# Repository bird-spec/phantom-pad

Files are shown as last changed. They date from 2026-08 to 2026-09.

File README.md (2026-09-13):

# phantom pad

this is the pcb for my phantom macropad. it's a little keyboard that doubles as a controller for my drone. twelve mechanical keys in a 3x4 matrix plus two rotary encoders, all running off a seeed xiao

the whole point is one board that's both a keyboard and a flight controller. rotate the encoders for throttle and yaw, and the four keys around each one act like a d-pad for direction. slide the top section off and it's just a normal macropad again

it's a two layer board. i wired the switches in a matrix so twelve keys only need seven pins instead of twelve, which left enough pins free for the two encoders. every switch has a diode so pressing three keys at once doesn't register a fourth one that isn't pressed

this was my first pcb ever. i learned kicad from nothing to make it. the hardest part was the routing, and figuring out that a matrix needs the rows and columns to actually reach the microcontroller, which sounds obvious but isn't when you're staring at a wall of green lines

made with the seeed xiao, cherry mx footprints, and alps ec11 encoders. firmware runs on qmk



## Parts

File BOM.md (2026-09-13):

# Phantom Pad - Bill of Materials

12-key macropad + 2 rotary encoders on a Seeed XIAO, 2-layer board (86.1 x 94.3 mm).

| # | Ref | Qty | Component | Footprint / Spec | Notes |
|---|-----|-----|---|---|---|
| 1 | U1 | 1 | Seeed Studio XIAO RP2040 | XIAO 14-pin hybrid, 2.54 mm | QMK (rp2040 bootloader); USB-C faces top edge |
| 2 | SW1-SW12 | 12 | Cherry MX (or MX-compatible) switch | Cherry MX PCB-mount | 3x4 matrix, 19.05 mm pitch |
| 3 | SW13, SW14 | 2 | Alps EC11 rotary encoder w/ switch | EC11, 6 mm D-shaft | throttle / yaw + push |
| 4 | D1-D12 | 12 | 1N4148 diode | DO-35, through-hole, vertical | one per switch (matrix anti-ghosting) |
| 5 | - | 1 | PCB | 2-layer, 86.1 x 94.3 mm | this repo (mk1.kicad_pcb) |
| 6 | - | 4 | M3 self-tapping screw, ~8 mm | - | base -> plate sandwich |
| 7 | - | 12 | Keycap (MX stem) | printed or DSA/OEM | printable |
| 8 | - | 2 | Encoder knob (6 mm D-shaft) | printed | printable |
| 9 | - | 1 | USB-C cable | - | power + flashing |

**Matrix:** 12 keys use 7 MCU pins (3 rows + 4 cols) instead of 12; the freed pins
drive the 2 encoders. Every switch has a diode so N-key rollover does not ghost.

_Component references (U1, SW1-SW14, D1-D12) verified against mk1.kicad_pcb

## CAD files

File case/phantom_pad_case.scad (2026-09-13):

// -------------------------------------------------------------
//  Phantom Pad - printable case (parametric, OpenSCAD)
//
//  Sandwich case: the PCB (no mounting holes) is captured between a
//  BASE tray and a top PLATE, held by 4 corner screws through standoffs.
//
//  All key/encoder cutouts are placed at the EXACT footprint positions
//  pulled from mk1.kicad_pcb (board origin = board min corner
//  94.492612, 33.242612 mm), so the plate lines up with the real board.
//
//  Board outline: 86.10 x 94.33 mm, XIAO USB faces the top edge (y=0).
//  Units: mm.
//
//  Render one part at a time with -D PART="base" | "plate" | "keycap" | "knob"
// -------------------------------------------------------------

PART = "base";           // base | plate | keycap | knob   (overridden by -D)
$fn  = 48;

// -- board --
BOARD_W = 86.10;
BOARD_H = 94.33;
PCB_T   = 1.6;           // 2-layer board thickness

// -- fit / walls --
SLACK   = 0.4;           // per-side clearance around the PCB in the tray
WALL    = 2.5;
FLOOR   = 2.0;
PLATE_T = 3.0;
STANDOFF_H = PCB_T + 0.6;   // lifts plate just above the board

// -- switches / encoders --
KEY_CUT = 14.0;          // Cherry MX plate cutout (14.0 mm square)
ENC_D   = 7.2;           // EC11 bushing hole
CAP     = 18.0;          // keycap footprint
CAP_H   = 7.0;

// USB-C slot on the top wall (XIAO connector faces y=0)
USB_W = 9.5; USB_H = 3.6;
XIAO_X = 42.91;          // U1 x, relative to board origin

// -- screw standoffs (M3 self-tap into plastic) --
SCREW_R   = 1.35;        // pilot for M3 self-tapping
BOSS_R    = 3.4;
BOSS_INSET = 6.0;
boss_xy = [
  [BOSS_INSET,            BOSS_INSET],
  [BOARD_W - BOSS_INSET,  BOSS_INSET],
  [BOSS_INSET,            BOARD_H - BOSS_INSET],
  [BOARD_W - BOSS_INSET,  BOARD_H - BOSS_INSET],
];

// -- EXACT switch positions (relative to board origin), from mk1.kicad_pcb --
keys = [
  [17.36,37.88],[36.32,37.88],[55.37,37.88],[74.42,37.88],  // row 1
  [17.27,56.93],[36.32,56.93],[55.37,56.93],[74.42,56.93],  // row 2
  [17.27,75.98],[36.32,75.98],[55.37,75.98],[74.42,75.98],  // row 3
];
encoders = [ [6.80,19.73], [64.14,20.21] ];   // SW14 (left), SW13 (right)

// tray inner cavity size (PCB + slack)
inner_w = BOARD_W + 2*SLACK;
inner_h = BOARD_H + 2*SLACK;
outer_w = inner_w + 2*WALL;
outer_h = inner_h + 2*WALL;

// ------------------------- BASE -------------------------
module base() {
  difference() {
    union() {
      // outer shell
      translate([-WALL-SLACK, -WALL-SLACK, 0])
        cube([outer_w, outer_h, FLOOR + STANDOFF_H + PCB_T]);
    }
    // hollow the cavity that holds the PCB (walls remain)
    translate([-SLACK, -SLACK, FLOOR])
      cube([inner_w, inner_h, STANDOFF_H + PCB_T + 1]);
    // USB-C slot in the top wall
    translate([XIAO_X - USB_W/2, -WALL-SLACK-0.1, FLOOR + STANDOFF_H])
      cube([USB_W, WALL + SLACK + 0.2, USB_H]);
  }
  // 4 corner standoffs the PCB rests against; screws self-tap here
  for (p = boss_xy)
    translate([p[0], p[1], FLOOR])
      difference() {
        cylinder(r = BOSS_R, h = STANDOFF_H);
        translate([0,0,-0.1]) cylinder(r = SCREW_R, h = STANDOFF_H + 0.2);
      }
}

// ------------------------- PLATE -------------------------
module plate() {
  difference() {
    // plate matches the outer footprint so it caps the tray
    translate([-WALL-SLACK, -WALL-SLACK, 0])
      cube([outer_w, outer_h, PLATE_T]);
    // 12 switch cutouts
    for (k = keys)
      translate([k[0]-KEY_CUT/2, k[1]-KEY_CUT/2, -0.1])
        cube([KEY_CUT, KEY_CUT, PLATE_T+0.2]);
    // 2 encoder bushing holes
    for (e = encoders)
      translate([e[0], e[1], -0.1])
        cylinder(d = ENC_D, h = PLATE_T+0.2);
    // 4 screw clearance holes (through)
    for (p = boss_xy)
      translate([p[0], p[1], -0.1])
        cylinder(r = SCREW_R + 0.35, h = PLATE_T+0.2);
  }
}

// ------------------- KEYCAP (simple, printable) -------------------
module keycap() {
  difference() {
    hull() {
      translate([-CAP/2,-CAP/2,0]) cube([CAP,CAP,0.1]);
      translate([-(CAP-3)/2,-(CAP-3)/2,CAP_H-0.1]) cube([CAP-3,CAP-3,0.1]);
    }
    // MX stem socket (+ cross)
    translate([0,0,-0.1]) {
      cylinder(d=5.6,h=4);
      translate([-2.05,-0.55,0]) cube([4.1,1.1,4]);
      translate([-0.55,-2.05,0]) cube([1.1,4.1,4]);
    }
  }
}

// ------------------- ENCODER KNOB -------------------
module knob() {
  KN_D=18; KN_H=14;
  difference() {
    union() {
      cylinder(d=KN_D,h=KN_H);
      for (i=[0:11]) rotate([0,0,i*30]) translate([KN_D/2-0.4,0,0]) cylinder(d=1.6,h=KN_H);
    }
    // D-shaft 6mm with flat
    translate([0,0,-0.1]) difference() {
      cylinder(d=6.1,h=KN_H-3);
      translate([1.5,-4,-0.2]) cube([4,8,KN_H]);   // flat
    }
  }
}

if      (PART == "base")   base();
else if (PART == "plate")  plate();
else if (PART == "keycap") keycap();
else if (PART == "knob")   knob();
else                       base();

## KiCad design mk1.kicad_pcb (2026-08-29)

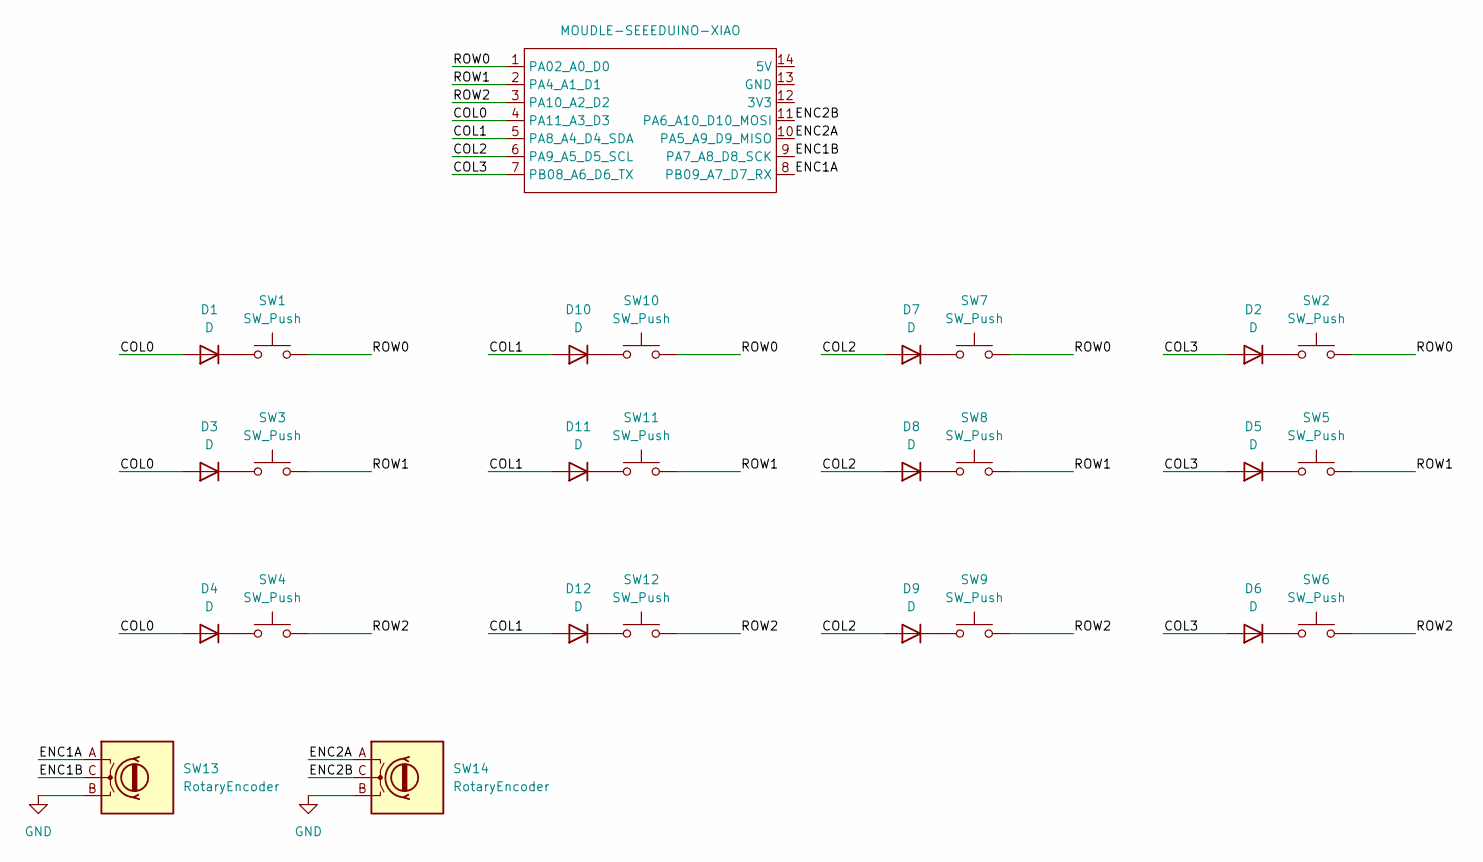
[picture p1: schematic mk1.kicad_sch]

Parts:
D1, D2, D3, D4, D5, D6, D7, D8, D9, D10, D11, D12: D; D_SOD-123
SW1, SW2, SW3, SW4, SW5, SW6, SW7, SW8, SW9, SW10, SW11, SW12: SW_Push; SW_Cherry_MX_1.00u_PCB
SW13, SW14: RotaryEncoder; RotaryEncoder_Alps_EC11E-Switch_Vertical_H20mm
U1: MOUDLE-SEEEDUINO-XIAO; XIAO-Generic-Hybrid-14P-2.54-21X17.8MM

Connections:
/COL0: D1.2 (A), D3.2 (A), D4.2 (A), U1.4 (PA11_A3_D3)
/COL1: D10.2 (A), D11.2 (A), D12.2 (A), U1.5 (PA8_A4_D4_SDA)
/COL2: D7.2 (A), D8.2 (A), D9.2 (A), U1.6 (PA9_A5_D5_SCL)
/COL3: D2.2 (A), D5.2 (A), D6.2 (A), U1.7 (PB08_A6_D6_TX)
/ENC1A: SW13.A, U1.8 (PB09_A7_D7_RX)
/ENC1B: SW13.C, U1.9 (PA7_A8_D8_SCK)
/ENC2A: SW14.A, U1.10 (PA5_A9_D9_MISO)
/ENC2B: SW14.C, U1.11 (PA6_A10_D10_MOSI)
/ROW0: SW1.2, SW2.2, SW7.2, SW10.2, U1.1 (PA02_A0_D0)
/ROW1: SW3.2, SW5.2, SW8.2, SW11.2, U1.2 (PA4_A1_D1)
/ROW2: SW4.2, SW6.2, SW9.2, SW12.2, U1.3 (PA10_A2_D2)
GND: SW13.B, SW14.B
unnamed: D1.1 (K), SW1.1
unnamed: D2.1 (K), SW2.1
unnamed: D3.1 (K), SW3.1
unnamed: D4.1 (K), SW4.1
unnamed: D5.1 (K), SW5.1
unnamed: D6.1 (K), SW6.1
unnamed: D7.1 (K), SW7.1
unnamed: D8.1 (K), SW8.1
unnamed: D9.1 (K), SW9.1
unnamed: D10.1 (K), SW10.1
unnamed: D11.1 (K), SW11.1
unnamed: D12.1 (K), SW12.1

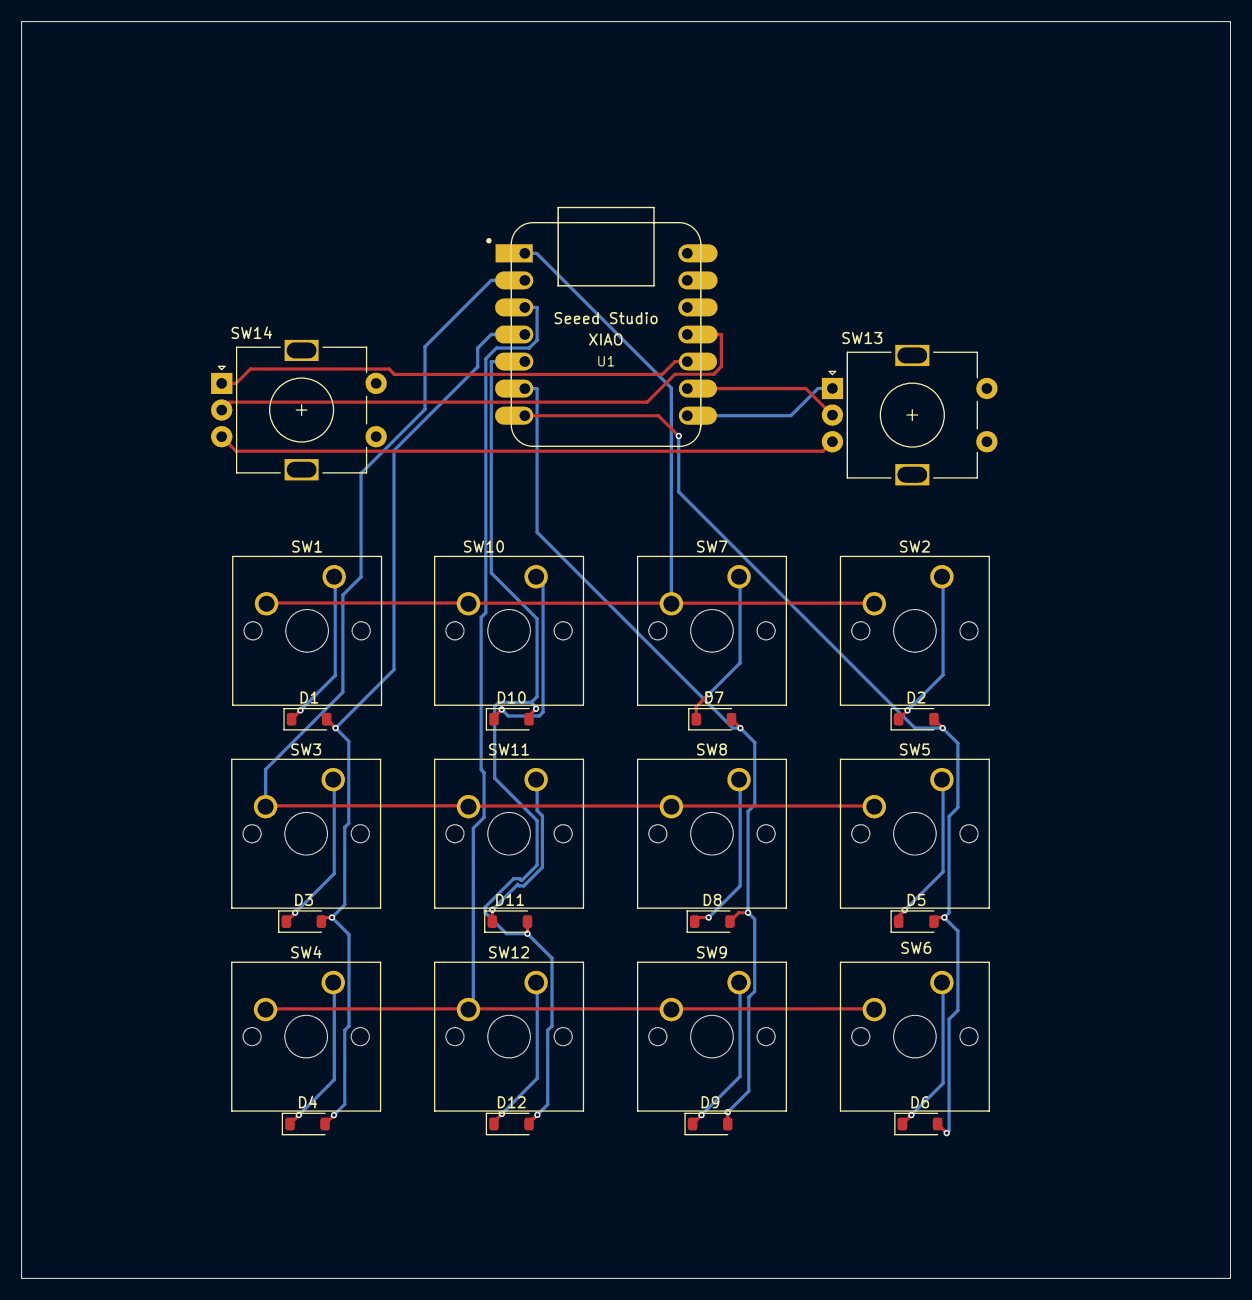
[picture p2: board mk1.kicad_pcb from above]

Board: 2 copper layers, 113.5 x 118.0 mm, 27 parts (0 on the bottom side), 24 nets.

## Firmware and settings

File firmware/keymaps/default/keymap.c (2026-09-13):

#include QMK_KEYBOARD_H

// PHANTOM pad — two layers.
//
//   DRONE : sends F13-F23, plus Ctrl+F13..F16 for the encoders. Nothing on a
//           PC uses those, so the host script can listen for them without
//           stealing keys you actually need. It turns each into a UDP packet
//           the drone already understands on port 5006.
//
//   PAD   : ordinary keys. Slide the rocker plate off, it is a macropad.
//
// The pad never talks to the drone directly - it is a USB device and the
// drone is on WiFi. The host script is the bridge.
//
// Why the modifiers: 8 directions + stop + 2 encoder buttons + 4 encoder
// turns is 15 distinct events, and F13-F24 only gives 12. Ctrl+F13..F16
// carries the four turns without colliding with anything.

enum layers { DRONE, PAD };

#define DR_LU  KC_F13   // left cluster  up
#define DR_LD  KC_F14   //               down
#define DR_LL  KC_F15   //               left
#define DR_LR  KC_F16   //               right
#define DR_RU  KC_F17   // right cluster up
#define DR_RD  KC_F18   //               down
#define DR_RL  KC_F19   //               left
#define DR_RR  KC_F20   //               right
#define DR_E1  KC_F21   // encoder 1 button
#define DR_E2  KC_F22   // encoder 2 button
#define DR_E3  KC_F24   // 12th key (bottom-right); spare drone action
#define DR_STOP KC_F23  // stabilise and land

#define DR_THRD LCTL(KC_F13)   // throttle down
#define DR_THRU LCTL(KC_F14)   // throttle up
#define DR_YAWL LCTL(KC_F15)   // yaw left
#define DR_YAWR LCTL(KC_F16)   // yaw right

const uint16_t PROGMEM keymaps[][MATRIX_ROWS][MATRIX_COLS] = {

  [DRONE] = LAYOUT(
      DR_LU,   DR_LD,   DR_LL,   DR_LR,
      DR_RU,   DR_RD,   DR_RL,   DR_RR,
      DR_STOP, DR_E1,   DR_E2,   DR_E3
  ),

  // Emergency stays on the same key and keeps sending the same code on both
  // layers. A stop button you have to be on the right layer to press is not
  // a stop button.
  [PAD] = LAYOUT(
      KC_W,    KC_S,    KC_A,    KC_D,
      KC_UP,   KC_DOWN, KC_LEFT, KC_RGHT,
      DR_STOP, KC_MPLY, KC_MUTE, KC_MNXT
  ),
};

// Hold stop and tap encoder 1's button to swap layers. Deliberately awkward -
// you do not want to land on the other layer mid-flight.
bool process_record_user(uint16_t keycode, keyrecord_t *record) {
  static bool stop_held = false;

  if (keycode == DR_STOP) { stop_held = record->event.pressed; return true; }

  if (stop_held && keycode == DR_E1 && record->event.pressed) {
    layer_invert(PAD);
    return false;                       // swallow it, do not send F21
  }
  return true;
}

#if defined(ENCODER_MAP_ENABLE)
const uint16_t PROGMEM encoder_map[][NUM_ENCODERS][2] = {
  //          encoder 1 - throttle          encoder 2 - yaw trim
  [DRONE] = { ENCODER_CCW_CW(DR_THRD, DR_THRU), ENCODER_CCW_CW(DR_YAWL, DR_YAWR) },
  [PAD]   = { ENCODER_CCW_CW(KC_VOLD, KC_VOLU), ENCODER_CCW_CW(KC_PGDN, KC_PGUP) },
};
#endif

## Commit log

2026-08-29 phantom macropad - 12 key matrix plus 2 encoders, first pcb
    [mk1.dsn, mk1.kicad_pcb, mk1.kicad_sch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]
2026-08-29 remove kicad lock files
2026-08-29 add landing page
2026-09-07 organize hackpad submission: CAD, PCB, firmware, production
2026-09-13 Add gerbers (full fab package)
    [mk1-B_Cu.gbr, mk1-B_Mask.gbr, mk1-B_Paste.gbr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]
2026-09-13 Enable encoder map in default rules
2026-09-13 Add Phantom Pad case design in OpenSCAD
    [phantom_pad_case.scad]
